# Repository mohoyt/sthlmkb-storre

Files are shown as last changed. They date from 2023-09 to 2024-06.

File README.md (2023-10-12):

# större
Större is an easy to build 75% keyboard using only through hole components. It uses a separate microcontroller (like the Pro Micro, Elite C or something RP2040 based) to enable flexibility in firmware and connectivity and to further simplify the soldering experience (no more tricksy USB ports). Demultiplexers and a custom matrix are used to enable the size and features of the board with only the pinouts of a pro micro. 

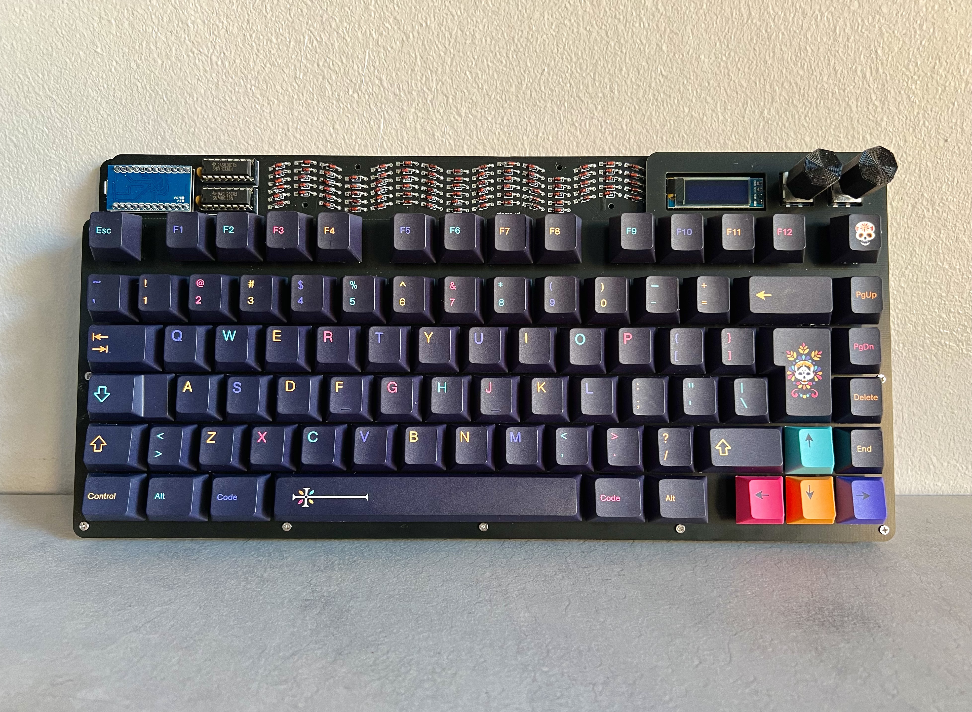
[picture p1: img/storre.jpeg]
större


**större kits are available for sale at [sthlmkb.com](https://sthlmkb.com/shop/storre-keyboard-kit/)**

[License](LICENSE)

Lagom is licensed under the [Creative Commons Attribution-NonCommercial 4.0 International license](https://creativecommons.org/licenses/by-nc/4.0/). This design as it stands in this repository may be freely reproduced, modified, and manufactured for PERSONAL USE ONLY and may not be reproduced in physical form for public sale. 

## Features
* Only through hole components for easy soldering
* Separate microcontroller using Pro micro, Elite C, Nice! Nano or equivalent footprint. So micro USB, USB-C or Bluetooth are all options!
* 2 rotary encoders
* OLED screen
* Optional underglow RGB lighting with a WS2812b light strip
* Multiple layout options including ISO, ANSI, split space (2.25u + 1.25u + 2.75u), 7u space, split left shift (1.25u + 1u) and stepped capslock ([layout]("http://www.keyboard-layout-editor.com/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,15&_x:0.25%3B&=2,15&_x:0.25%3B&=0,0%0A%0A%0A%0A%0A%0A%0A%0A%0Ae&=0,1%0A%0A%0A%0A%0A%0A%0A%0A%0Ae%3B&@_y:0.25%3B&=0,0&=0,1&=0,2&=0,3&=0,4&=0,5&=0,6&=0,7&=0,8&=0,9&=0,10&=0,11&=0,12&_w:2%3B&=0,14%0A%0A%0A0,0&=0,15&_x:0.25%3B&=1,0%0A%0A%0A%0A%0A%0A%0A%0A%0Ae&=1,1%0A%0A%0A%0A%0A%0A%0A%0A%0Ae%3B&@_w:1.5%3B&=1,0&=1,1&=1,2&=1,3&=1,4&=1,5&=1,6&=1,7&=1,8&=1,9&=1,10&=1,11&=1,12&_w:1.5%3B&=1,13%0A%0A%0A1,0&=1,14%3B&@_w:1.75%3B&=2,0&=2,1&=2,2&=2,3&=2,4&=2,5&=2,6&=2,7&=2,8&=2,9&=2,10&=2,11&_w:2.25%3B&=2,13%0A%0A%0A1,0&=2,14%3B&@_w:2.25%3B&=3,0%0A%0A%0A2,0&=3,2&=3,3&=3,4&=3,5&=3,6&=3,7&=3,8&=3,9&=3,10&=3,11&_w:1.75%3B&=3,12&=3,13&=3,14%3B&@_w:1.25%3B&=4,0%0A%0A%0A3,0&_w:1.25%3B&=4,1%0A%0A%0A3,0&_w:1.25%3B&=4,2%0A%0A%0A3,0&_w:6.25%3B&=4,6%0A%0A%0A3,0&_w:1.25%3B&=4,10%0A%0A%0A3,0&_w:1.25%3B&=4,11%0A%0A%0A3,0&_x:0.5%3B&=4,12&=4,13&=4,14%3B&@_y:0.5&w:1.25%3B&=4,0%0A%0A%0A3,1&_w:1.25%3B&=4,1%0A%0A%0A3,1&_w:1.25%3B&=4,2%0A%0A%0A3,1&_w:2.25%3B&=4,4%0A%0A%0A3,1&_w:1.25%3B&=4,6%0A%0A%0A3,1&_w:2.75%3B&=4,8%0A%0A%0A3,1&_w:1.25%3B&=4,10%0A%0A%0A3,1&_w:1.25%3B&=4,11%0A%0A%0A3,1%3B&@_y:-0.25&x:15&w:1.25&h:2&w2:1.5&h2:1&x2:-0.25%3B&=2,13%0A%0A%0A1,1%3B&@_y:-0.75&w:1.5%3B&=4,0%0A%0A%0A3,2&=4,1%0A%0A%0A3,2&_w:1.5%3B&=4,2%0A%0A%0A3,2&_w:7%3B&=4,6%0A%0A%0A3,2&_w:1.5%3B&=4,11%0A%0A%0A3,2%3B&@_y:-0.25&x:14%3B&=2,12%0A%0A%0A1,1%3B&@_w:1.25%3B&=3,0%0A%0A%0A2,1&=3,1%0A%0A%0A2,1&_x:9.75%3B&=0,13%0A%0A%0A0,1&=0,14%0A%0A%0A0,1"))
* Open and visible components (in the style of Plaid, Romac etc)
* Simple, beautiful and flexible sandwich case out of FR4 (pcb material)

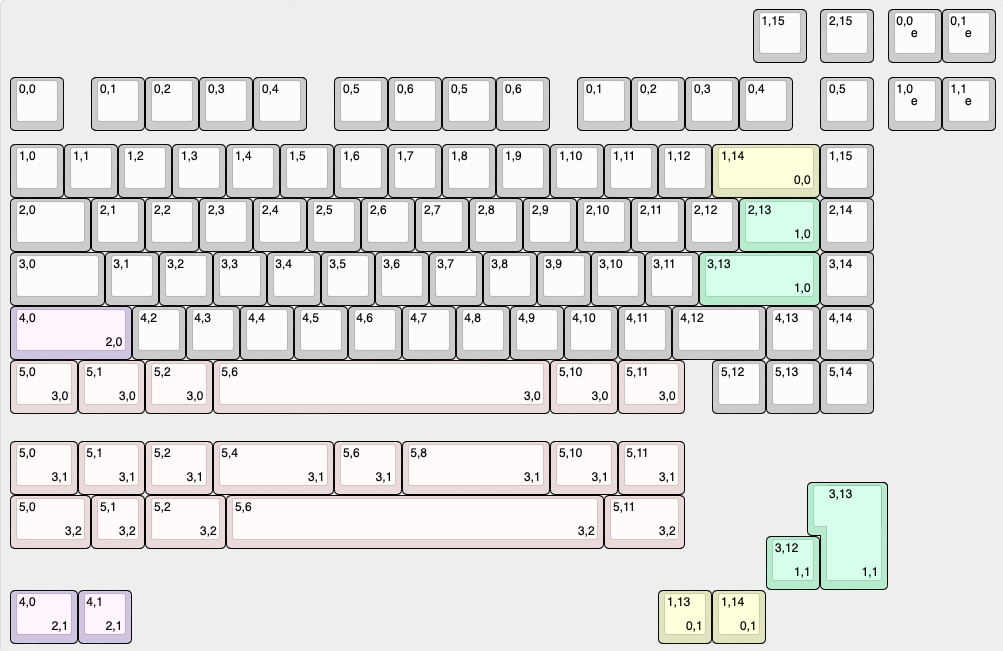
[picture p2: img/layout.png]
lagom layout storre layout


## Components required 
* PCB
* FR4 Switch plate
* FR4 Base 
* Controller (I used a Pro Micro in the guide but anything that shares the footprint and pinout will be fine e.g. Elite C, Nice! Nano, or something RP2040 powered!)
* Diodes 1N4148 (88)
* 0.1μF Capacitor (2)
* 16 pin IC socket (2)
* IC (74HC138N) demultiplexer (2)
* Switches (5 pin MX footprint) (up to 87 depending on layout)
* Rotary encoders (2)
* Rotary encoder knobs (2)
* 0.91" OLED screen
* 10mm M2 Standoffs (9 required if mounting the base to the plate)
* 6mm x M2 screws for attaching the standoffs to the plate/base (2 per standoff so 18 total)
* Acrylic cover for the components at the top (optional, not included)
* Stabilisers (PCB mount) (5 x 2u or 3 x 2u + 6.25u or 3 x 2u + 7u depending on layout)
* Rubber feet for the base

[Build guide available here](https://sthlmkb.com/2023/10/storre-build-guide/)

[Build timelapse available here](https://youtu.be/ZGffb1hYfCY)

[Firmware available here](firmware)

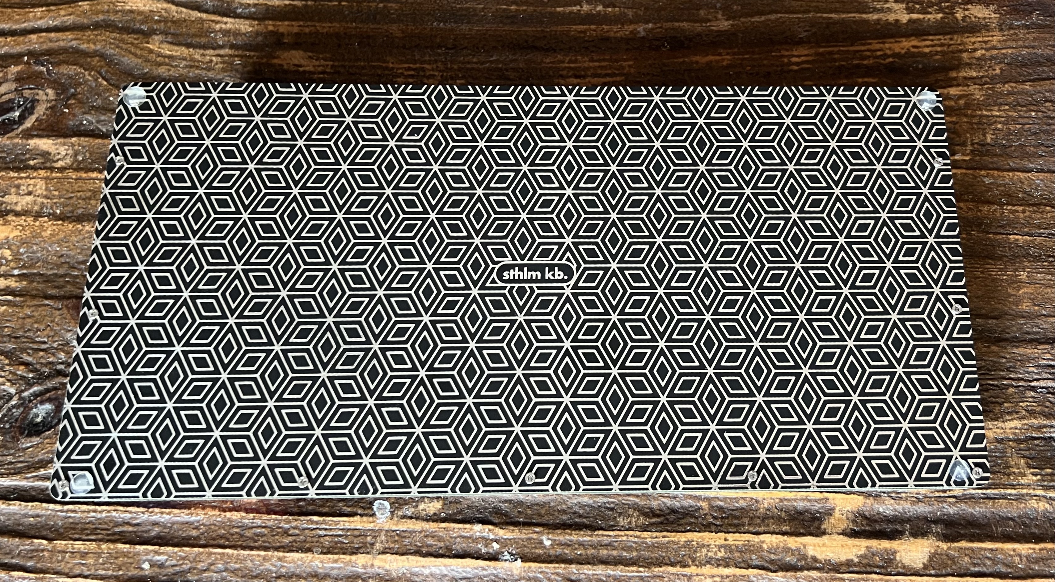
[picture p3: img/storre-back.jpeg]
större base större back


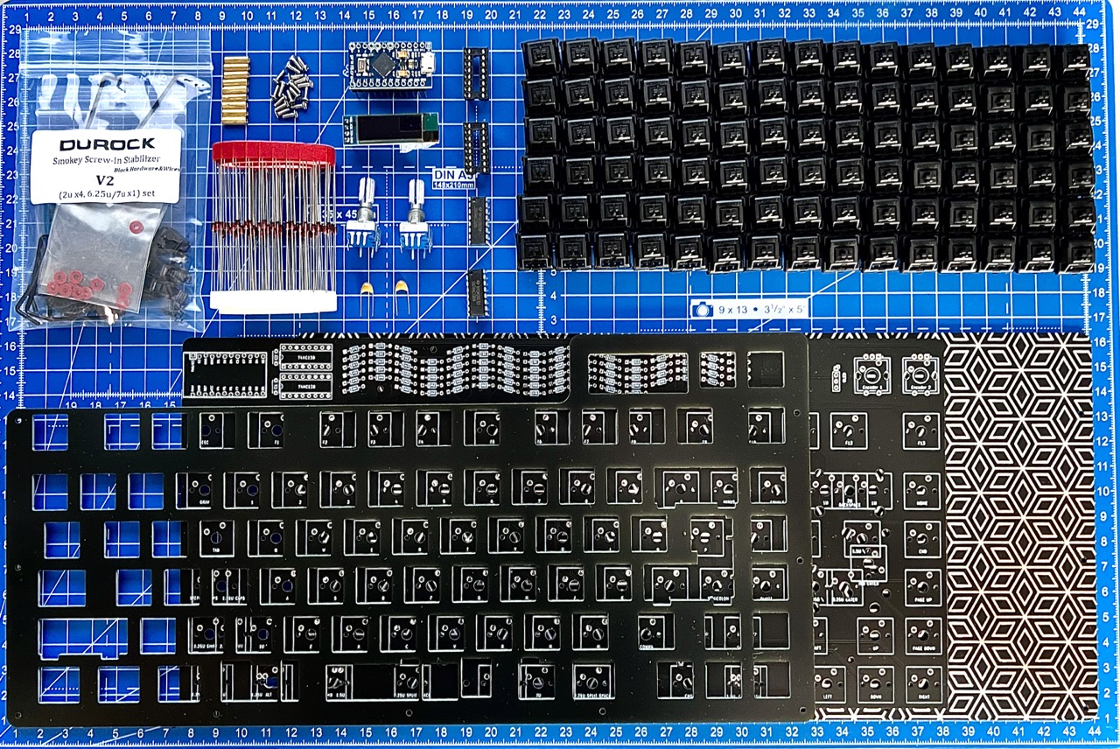
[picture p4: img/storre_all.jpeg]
större större pcb


## Known issues 
* Initial batch of v1 boards did not have side switch mounting holes on the tab key. You will have to trim them for this key if you are using 5 pin switches. 
* Initial batch of v1 boards says storre instead of större at the top of the board

## Where to buy
större kits are available for sale exclusively at [sthlmkb.com](https://sthlmkb.com/shop/storre-keyboard-kit/)

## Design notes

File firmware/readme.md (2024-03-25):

# större

Större is an easy to build 75% keyboard using only through hole components. It uses a separate microcontroller (like the Pro Micro or Elite C) to enable flexibility in connectivity and to further simplify the soldering experience (no more tricksy USB ports).

* Keyboard Maintainer: [mohoyt](https://github.com/mohoyt)
* Hardware Supported: storre, Pro Micro, Elite-C, Puchi-C, Nice!Nano and more...
* Hardware Availability: [sthlm kb](https://sthlmkb.com)

Make example for this keyboard (after setting up your build environment):

    make sthlmkb/storre:default

See the [build environment setup](https://docs.qmk.fm/#/getting_started_build_tools) and the [make instructions](https://docs.qmk.fm/#/getting_started_make_guide) for more information. Brand new to QMK? Start with our [Complete Newbs Guide](https://docs.qmk.fm/#/newbs).

Alternatively flash one of the precompiled hexes. There's a few options:
* One's a Vial compatible image one with bongocat
* Another's a Vial image with a WPM graph on it

The .hex file is if you're using an Atmel chip (like a traditional Pro Micro). The uf2 files are for a RP2040 style pro micro like the Helios. 

Once you've flashed one of the precompiled hexes, open the Vial app or head to [https://vial.rocks](https://vial.rocks) to configure your board. 

## RGB Lighting

It is possible to add RGB lighting to the Större. There's a couple changes that you need to make to info.json to make it happen before recompiling the firmware. These changes are:
* Adding `"rgblight": true` to the feature section
* Adding a `rgblight` and `ws2812` section. More info [here](https://docs.qmk.fm/#/feature_rgblight) too.
```    
"rgblight": {
        "led_count": 11,
        "sleep": true,
        "hue_steps": 10,
        "saturation_steps": 10,
        "brightness_steps": 10,
        "animations": {
            "rainbow_mood": true,
            "static_gradient": true
        }
       },
    "ws2812": {
        "pin": "F6"
        }
```
* You'll then need to assign some keys to toggle on the RGB and change modes etc. This is easiest done in Vial if you've flashed a Vial compatible image. 
* Bear in mind that the RGB feature takes up some space so you may run out of space if you're compiling this for a Pro Micro

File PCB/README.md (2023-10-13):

# större
Större is an easy to build 75% keyboard using only through hole components. It uses a separate microcontroller (like the Pro Micro, Elite C or something RP2040 based) to enable flexibility in firmware and connectivity and to further simplify the soldering experience (no more tricksy USB ports). Demultiplexers and a custom matrix are used to enable the size and features of the board with only the pinouts of a pro micro. 

större

**större kits are available for sale at [sthlmkb.com](https://sthlmkb.com/shop/storre-keyboard-kit/)**

[License](LICENSE)

Lagom is licensed under the [Creative Commons Attribution-NonCommercial 4.0 International license](https://creativecommons.org/licenses/by-nc/4.0/). This design as it stands in this repository may be freely reproduced, modified, and manufactured for PERSONAL USE ONLY and may not be reproduced in physical form for public sale. 

## Designs that are here:
* Storre (i.e this directory) - this is the main PCB
* Storre Plate (`storre_plate`) - this is the plate that holds the switches and goes above the PCB
* Storre Base (`storre_base`) - this is the base of the board and goes below the PCB

## Some useful images/documentation:

layout

This the key layout and all option layouts exported from keyboard-layout-editor

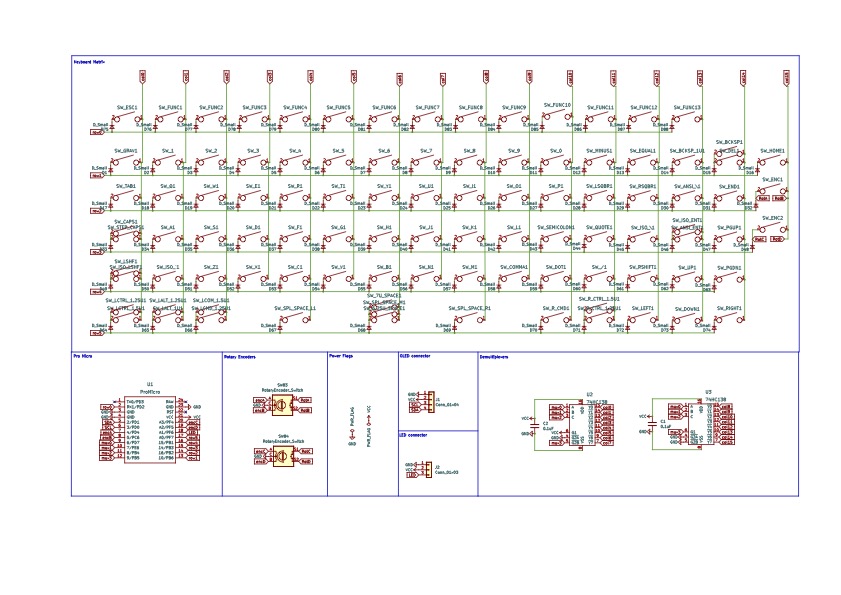
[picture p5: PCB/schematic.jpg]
schematic


This is the schematic of the keyboard. See a higher res version [here](schematic.pdf)

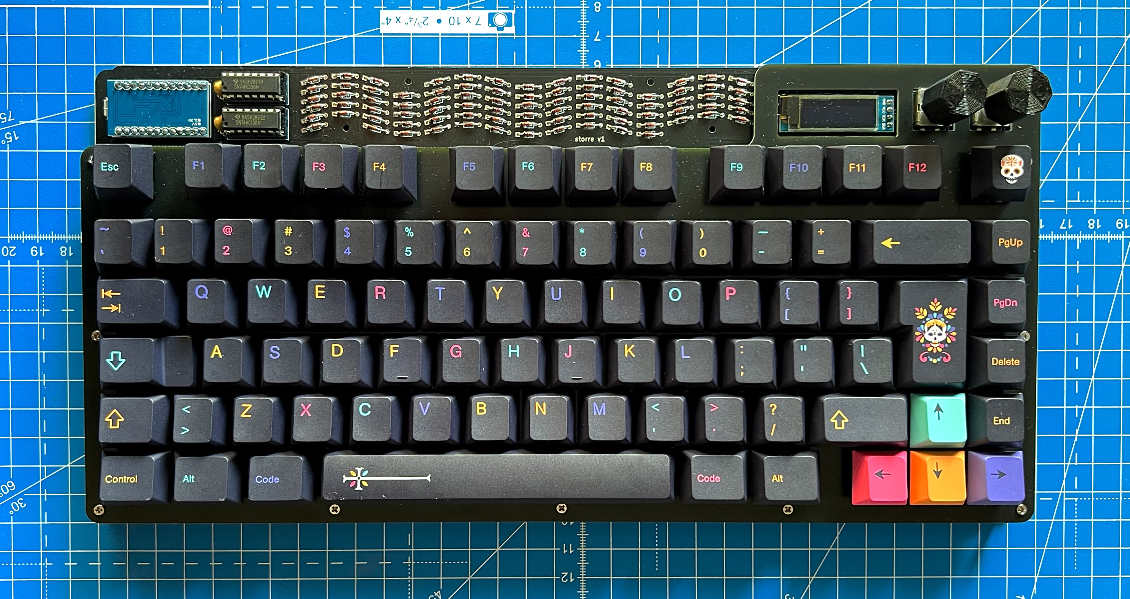
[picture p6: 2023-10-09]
img/storre-blue.jpeg

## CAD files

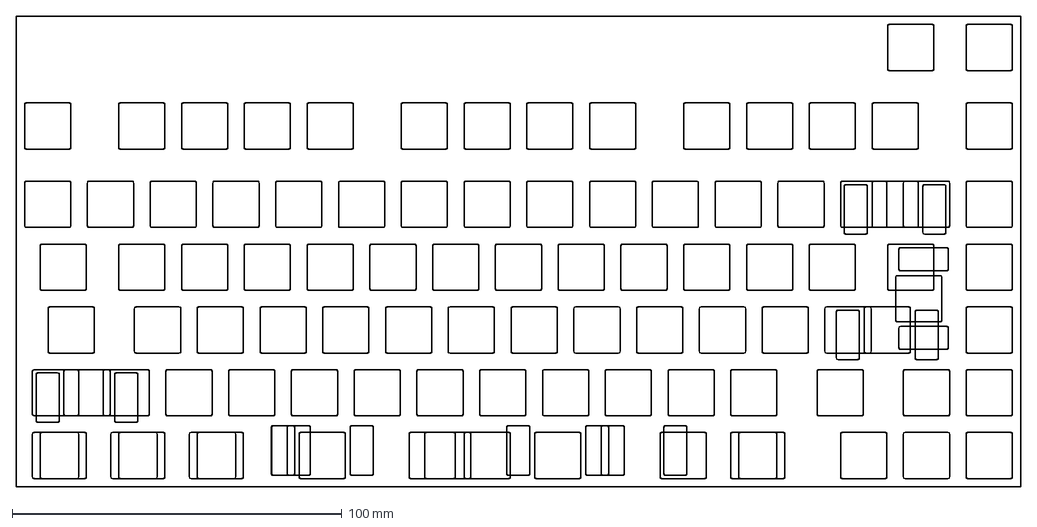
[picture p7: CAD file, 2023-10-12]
PCB/storre plate original.dxf
304.8 x 142.9 mm

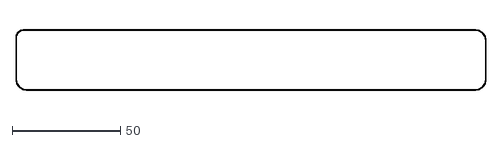
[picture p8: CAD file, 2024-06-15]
PCB/storre_window/outputs/storre_window-Edge_Cuts.dxf
216.7 x 27.8

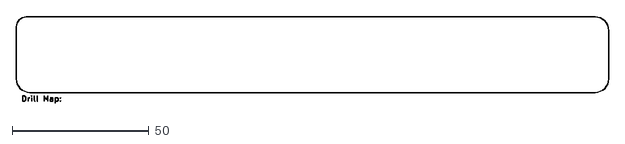
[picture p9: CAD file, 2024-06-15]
PCB/storre_window/outputs/storre_window-PTH-drl_map.dxf
216.5 x 31.5

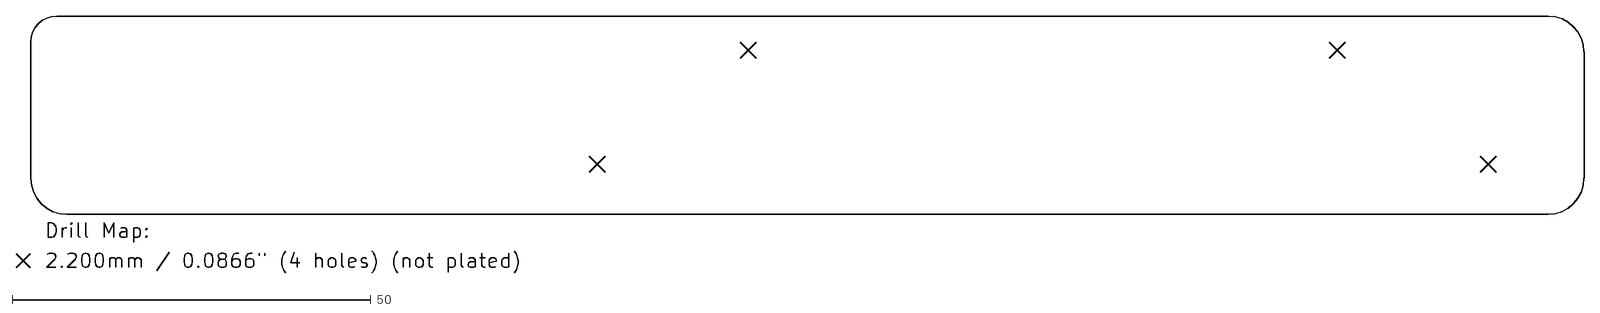
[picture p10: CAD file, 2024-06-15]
PCB/storre_window/outputs/storre_window-NPTH-drl_map.dxf
218.6 x 35.8

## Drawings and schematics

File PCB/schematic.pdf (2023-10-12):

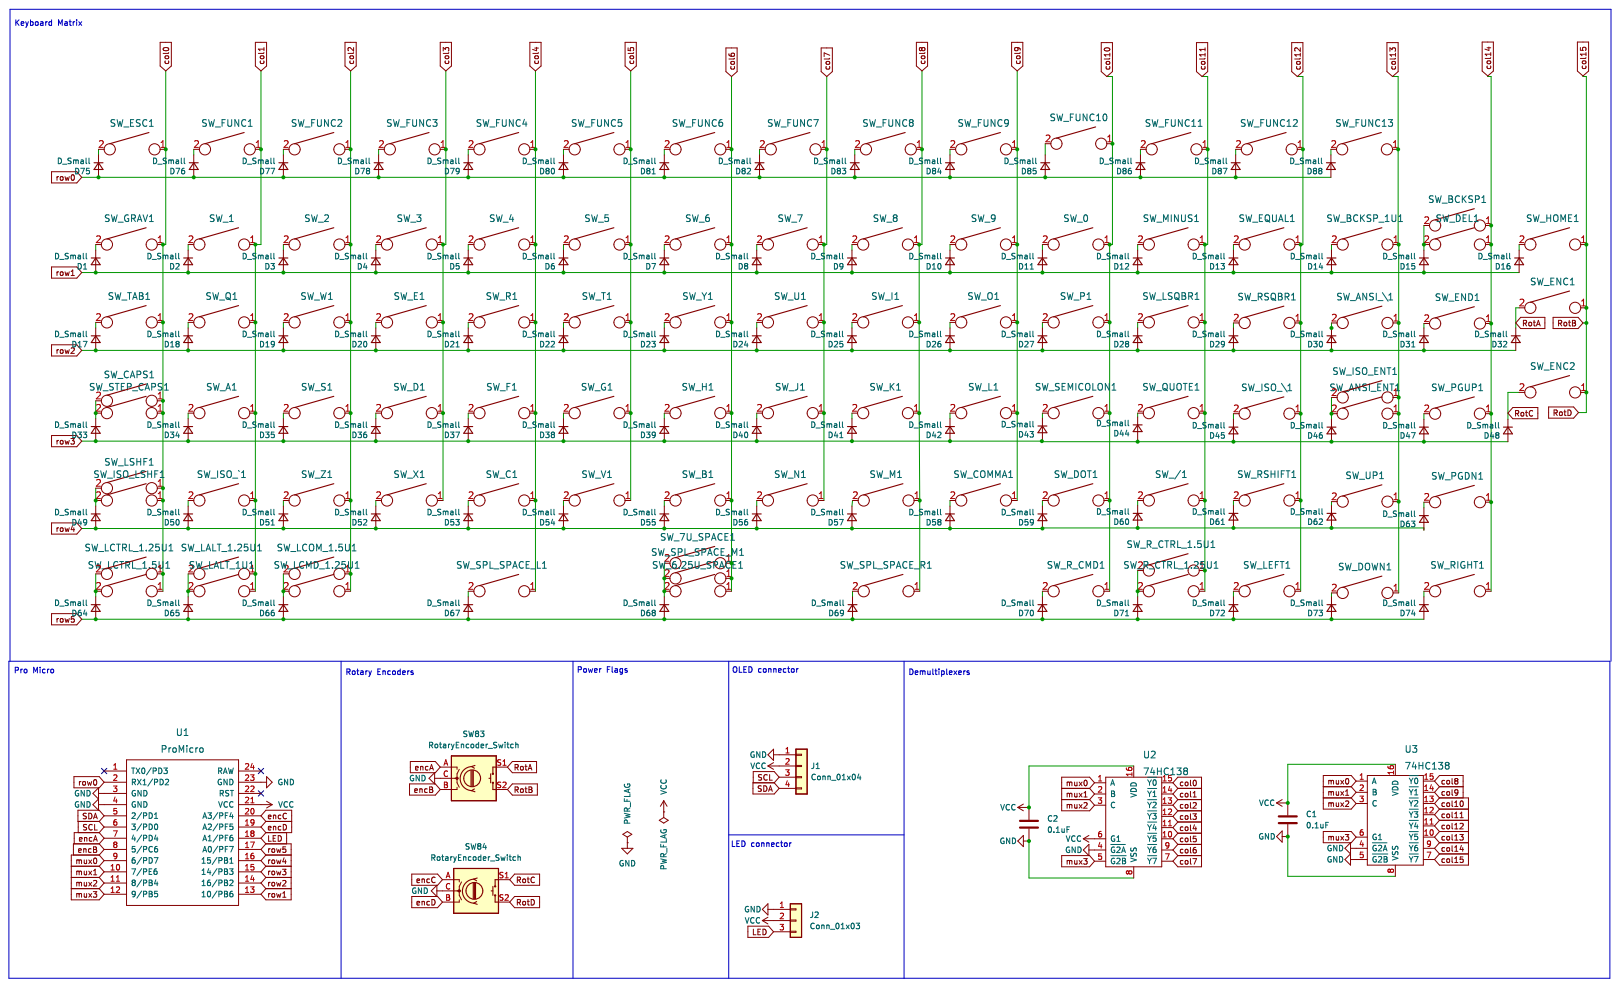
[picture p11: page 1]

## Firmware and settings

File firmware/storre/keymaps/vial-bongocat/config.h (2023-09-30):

#pragma once

#define VIAL_KEYBOARD_UID {0xD8, 0x27, 0xC9, 0x36, 0x3D, 0x71, 0xF2, 0x13}

#define ENCODERS_PAD_A { C6, F5 }
#define ENCODERS_PAD_B { D4, F4 }

#define VIAL_COMBO_ENTRIES 2
#define VIAL_TAP_DANCE_ENTRIES 4
#define VIAL_KEY_OVERRIDE_ENTRIES 2
#define DYNAMIC_KEYMAP_LAYER_COUNT 2
#define VIAL_UNLOCK_COMBO_ROWS { 0, 4 }
#define VIAL_UNLOCK_COMBO_COLS { 0, 14 }
#define VIAL_ENCODER_DEFAULT { KC_VOLD, KC_VOLU, KC_MPRV, KC_MNXT, KC_TRNS, KC_TRNS, KC_TRNS, KC_TRNS }

// OLED setup for bongocat
#define IDLE_FRAMES 5
#define IDLE_SPEED 30
#define TAP_FRAMES 2
#define TAP_SPEED 40
#define ANIM_FRAME_DURATION 200
#define ANIM_SIZE 512

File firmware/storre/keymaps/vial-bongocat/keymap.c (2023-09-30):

/* Copyright 2022 mohoyt
 *
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
 * You should have received a copy of the GNU General Public License
 * along with this program.  If not, see <http://www.gnu.org/licenses/>.
 */
#include QMK_KEYBOARD_H
#include <stdio.h>

static long int oled_timeout = 600000; // 10 minutes
bool gui_on = true;
char wpm_str[10];
uint32_t anim_timer = 0;
uint32_t anim_sleep = 0;
uint8_t current_idle_frame = 0;
uint8_t current_tap_frame = 0;

const uint16_t PROGMEM keymaps[][MATRIX_ROWS][MATRIX_COLS] = {
  [0] = LAYOUT_base(
    KC_ESC,  KC_F1,   KC_F2,   KC_F3,   KC_F4,   KC_F5,   KC_F6,   KC_F7,   KC_F8,   KC_F9,   KC_F10,  KC_F11,  KC_F12,           KC_F13,
    KC_GRV,  KC_1,    KC_2,    KC_3,    KC_4,    KC_5,    KC_6,    KC_7,    KC_8,    KC_9,    KC_0,    KC_MINS, KC_EQL,  KC_BSPC, KC_HOME,
    KC_TAB,  KC_Q,    KC_W,    KC_E,    KC_R,    KC_T,    KC_Y,    KC_U,    KC_I,    KC_O,    KC_P,    KC_LBRC, KC_RBRC, KC_BSLS, KC_END, KC_MPLY,
    KC_CAPS, KC_A,    KC_S,    KC_D,    KC_F,    KC_G,    KC_H,    KC_J,    KC_K,    KC_L,    KC_SCLN, KC_QUOT,          KC_ENT,  KC_PGUP,KC_MUTE,
    KC_LSFT,          KC_Z,    KC_X,    KC_C,    KC_V,    KC_B,    KC_N,    KC_M,    KC_COMM, KC_DOT,  KC_SLSH, KC_RSFT, KC_UP,   KC_PGDN,
    KC_LCTL, KC_LGUI, KC_LALT,                            KC_SPC,                             KC_RALT,   MO(1), KC_LEFT, KC_DOWN, KC_RGHT ),

  [1] = LAYOUT_base(
    KC_ESC,  KC_F1,   KC_F2,   KC_F3,   KC_F4,   KC_F5,   KC_F6,   KC_F7,   KC_F8,   KC_F9,   KC_F10,  KC_F11,  KC_F12,           KC_F13,
    KC_GRV,  KC_1,    KC_2,    KC_3,    KC_4,    KC_5,    KC_6,    KC_7,    KC_8,    KC_9,    KC_0,    KC_MINS, KC_EQL,  KC_BSPC, KC_HOME,
    KC_TAB,  KC_Q,    KC_W,    KC_E,    KC_R,    KC_T,    KC_Y,    KC_U,    KC_I,    KC_O,    KC_P,    KC_LBRC, KC_RBRC, KC_BSLS, KC_END, KC_MPLY,
    KC_CAPS, KC_A,    KC_S,    KC_D,    KC_F,    KC_G,    KC_H,    KC_J,    KC_K,    KC_L,    KC_SCLN, KC_QUOT,          KC_ENT,  KC_PGUP,KC_MUTE,
    KC_LSFT,          KC_Z,    KC_X,    KC_C,    KC_V,    KC_B,    KC_N,    KC_M,    KC_COMM, KC_DOT,  KC_SLSH, KC_RSFT, KC_UP,   KC_PGDN,
    KC_LCTL, KC_LGUI, KC_LALT,                            KC_SPC,                             KC_RALT, KC_RCTL, KC_LEFT, KC_DOWN, KC_RGHT )
};

//Encoder map
#if defined(ENCODER_MAP_ENABLE)
const uint16_t PROGMEM encoder_map[][2][2] = {
    [0] =   { ENCODER_CCW_CW(KC_MPRV, KC_MNXT), ENCODER_CCW_CW(KC_VOLD, KC_VOLU)  },
    [1] =  { ENCODER_CCW_CW(KC_MPRV, KC_MNXT), ENCODER_CCW_CW(KC_VOLD, KC_VOLU)  }
};
#endif

//OLED stuff here
#ifdef OLED_ENABLE
oled_rotation_t oled_init_user(oled_rotation_t rotation) {
   return OLED_ROTATION_180;  // flips the display 180 degrees
}

static void render_anim(void) {

    // Idle animation
    static const char PROGMEM idle[IDLE_FRAMES][ANIM_SIZE] = {

        {
            0,0,0,0,0,0,0,0,0,0,0,0,0,0,0,0,0,0,0,0,0,0,0,0,0,0,0,0,0,0,0,0,0,0,0,0,0,0,0,0,0,0,0,0,0,0,0,0,0,0,0,0,0,0,0,0,0,0,128,64,64,32,32,32,32,16,16,16,16,16,8,8,4,4,4,8,48,64,128,0,0,0,0,0,0,0,0,0,0,0,0,0,0,0,0,0,0,0,0,0,0,0,0,0,0,0,0,0,0,0,0,0,0,0,0,0,0,0,0,0,0,0,0,0,0,128,128,128,0,0,0,0,0,0,0,0,0,0,0,0,0,0,0,0,0,0,0,0,0,0,0,0,0,0,0,0,0,0,0,0,0,0,0,0,0,0,0,0,0,0,0,0,0,0,0,0,0,24,100,130,2,2,2,2,2,1,0,0,0,0,128,128,0,0,0,0,0,0,0,0,0,128,0,48,48,0,192,193,193,194,4,8,16,32,64,128,0,0,0,128,128,128,128,64,64,
            64,64,32,32,32,32,16,16,16,16,8,8,8,8,8,4,4,4,4,4,2,2,2,2,1,1,1,1,0,0,0,0,0,0,0,0,0,0,0,0,0,0,0,0,0,0,0,0,0,0,0,0,0,0,0,0,0,0,0,0,0,0,0,0,0,0,0,0,0,0,0,0,0,0,0,0,0,0,0,192,56,4,3,0,0,0,0,0,0,0,12,12,12,13,1,0,64,160,33,34,18,17,17,17,9,8,8,8,8,4,4,8,8,16,16,16,16,16,17,15,1,1,0,0,0,0,0,0,0,0,0,0,0,0,0,0,0,0,0,0,0,0,0,0,0,0,0,0,0,0,0,0,0,0,0,0,0,0,0,0,0,0,0,0,0,0,0,0,0,0,0,0,0,0,0,0,128,128,128,128,128,64,64,64,64,64,32,32,32,32,32,16,16,16,16,16,8,8,8,8,8,4,4,4,4,4,2,3,2,2,1,1,1,1,1,1,2,2,4,4,8,8,8,8,8,7,
            0,0,0,0,0,0,0,0,0,0,0,0,0,0,0,0,0,0,0,0,0,0,0,0,0,0,0,0,0,0,0,0,0,0,0,0,0,0,0,0,0,0,0,0,0,0,0,0,0,0,0,0,0,0,0,0,0,0,0,0,0
        },

        {
            0,0,0,0,0,0,0,0,0,0,0,0,0,0,0,0,0,0,0,0,0,0,0,0,0,0,0,0,0,0,0,0,0,0,0,0,0,0,0,0,0,0,0,0,0,0,0,0,0,0,0,0,0,0,0,0,0,0,128,64,64,32,32,32,32,16,16,16,16,16,8,8,4,4,4,8,48,64,128,0,0,0,0,0,0,0,0,0,0,0,0,0,0,0,0,0,0,0,0,0,0,0,0,0,0,0,0,0,0,0,0,0,0,0,0,0,0,0,0,0,0,0,0,0,0,128,128,128,0,0,0,0,0,0,0,0,0,0,0,0,0,0,0,0,0,0,0,0,0,0,0,0,0,0,0,0,0,0,0,0,0,0,0,0,0,0,0,0,0,0,0,0,0,0,0,0,0,24,100,130,2,2,2,2,2,1,0,0,0,0,128,128,0,0,0,0,0,0,0,0,0,128,0,48,48,0,192,193,193,194,4,8,16,32,64,128,0,0,0,128,128,128,128,64,64,
            64,64,32,32,32,32,16,16,16,16,8,8,8,8,8,4,4,4,4,4,2,2,2,2,1,1,1,1,0,0,0,0,0,0,0,0,0,0,0,0,0,0,0,0,0,0,0,0,0,0,0,0,0,0,0,0,0,0,0,0,0,0,0,0,0,0,0,0,0,0,0,0,0,0,0,0,0,0,0,192,56,4,3,0,0,0,0,0,0,0,12,12,12,13,1,0,64,160,33,34,18,17,17,17,9,8,8,8,8,4,4,8,8,16,16,16,16,16,17,15,1,1,0,0,0,0,0,0,0,0,0,0,0,0,0,0,0,0,0,0,0,0,0,0,0,0,0,0,0,0,0,0,0,0,0,0,0,0,0,0,0,0,0,0,0,0,0,0,0,0,0,0,0,0,0,0,128,128,128,128,128,64,64,64,64,64,32,32,32,32,32,16,16,16,16,16,8,8,8,8,8,4,4,4,4,4,2,3,2,2,1,1,1,1,1,1,2,2,4,4,8,8,8,8,8,
            7,0,0,0,0,0,0,0,0,0,0,0,0,0,0,0,0,0,0,0,0,0,0,0,0,0,0,0,0,0,0,0,0,0,0,0,0,0,0,0,0,0,0,0,0,0,0,0,0,0,0,0,0,0,0,0,0,0,0,0,0,0
        },

        {
            0,0,0,0,0,0,0,0,0,0,0,0,0,0,0,0,0,0,0,0,0,0,0,0,0,0,0,0,0,0,0,0,0,0,0,0,0,0,0,0,0,0,0,0,0,0,0,0,0,0,0,0,0,0,0,0,0,0,0,128,128,64,64,64,64,32,32,32,32,16,8,4,2,2,4,24,96,128,0,0,0,0,0,0,0,0,0,0,0,0,0,0,0,0,0,0,0,0,0,0,0,0,0,0,0,0,0,0,0,0,0,0,0,0,0,0,0,0,0,0,0,0,0,0,0,128,128,128,0,0,0,0,0,0,0,0,0,0,0,0,0,0,0,0,0,0,0,0,0,0,0,0,0,0,0,0,0,0,0,0,0,0,0,0,0,0,0,0,0,0,0,0,0,0,0,0,0,60,194,1,1,2,2,4,4,2,1,0,0,0,0,0,0,0,0,0,0,0,0,0,0,0,0,96,96,0,129,130,130,132,8,16,32,64,128,0,0,0,0,128,128,128,128,64,64,64,64,32,
            32,32,32,16,16,16,16,8,8,8,8,8,4,4,4,4,4,2,2,2,2,1,1,1,1,0,0,0,0,0,0,0,0,0,0,0,0,0,0,0,0,0,0,0,0,0,0,0,0,0,0,0,0,0,0,0,0,0,0,0,0,0,0,0,0,0,0,0,0,0,0,0,0,0,0,0,128,112,25,6,0,0,0,0,0,0,0,24,24,24,27,3,0,64,160,34,36,20,18,18,18,11,8,8,8,8,5,5,9,9,16,16,16,16,16,17,15,1,1,0,0,0,0,0,0,0,0,0,0,0,0,0,0,0,0,0,0,0,0,0,0,0,0,0,0,0,0,0,0,0,0,0,0,0,0,0,0,0,0,0,0,0,0,0,0,0,0,0,0,0,0,0,0,128,128,128,128,128,64,64,64,64,64,32,32,32,32,32,16,16,16,16,16,8,8,8,8,8,4,4,4,4,4,2,3,2,2,1,1,1,1,1,1,2,2,4,4,8,8,8,8,8,7,0,0,0,
            0,0,0,0,0,0,0,0,0,0,0,0,0,0,0,0,0,0,0,0,0,0,0,0,0,0,0,0,0,0,0,0,0,0,0,0,0,0,0,0,0,0,0,0,0,0,0,0,0,0,0,0,0,0,0,0,0,0
        },
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

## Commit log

2023-10-12 pcb files added
    [storre plate original.dxf, storre.kicad_sch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]
2024-06-15 Större window added
    [storre_window-Edge_Cuts.dxf, storre_window-NPTH-drl_map.dxf, storre_window-PTH-drl_map.dxf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]

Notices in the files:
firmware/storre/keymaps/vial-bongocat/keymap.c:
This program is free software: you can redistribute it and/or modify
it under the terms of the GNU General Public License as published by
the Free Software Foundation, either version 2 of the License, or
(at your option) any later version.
